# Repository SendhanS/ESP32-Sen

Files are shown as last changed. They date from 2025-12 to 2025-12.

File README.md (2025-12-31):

# ESP32-Sen
A compact ESP32-S3-MINI-1-N8 development board with USB-C (ESD protected), a 4-layer PCB stack-up (signal / GND / power / signal), and 3.3 V regulation using the TLV75801. Includes GPIO buttons, a WS2812B status LED, and space for an onboard I²C OLED breakout.
The board is intended for learning, experimentation, and portfolio demonstration of embedded systems and PCB design practices.
Status: Not yet tested.
The design is functional in theory but may require revisions and improvements after bring-up.

**Overview**

This board provides a clean ESP32-S3 core with USB-C connectivity, proper ESD protection, a structured 4-layer PCB stack-up, and expansion options for basic UI and peripherals. The goal was to move beyond simple 2-layer hobby boards and design something closer to real-world embedded hardware.

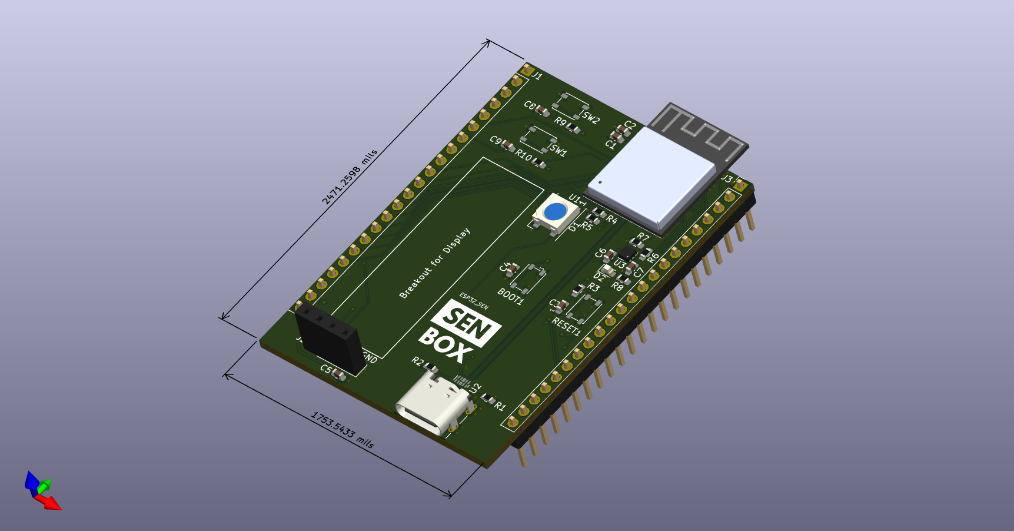
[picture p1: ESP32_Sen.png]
3D render


**Key Features**

ESP32-S3-MINI-1-N8 module

USB-C connector (USB4105)

Differential USB D+ / D− routing

ESD protection using D3V3XA4B10LP TVS diodes

TLV75801 linear regulator (5 V USB → 3.3 V)

4-layer PCB stack-up:

Top: Signal + components

Inner 1: Solid GND plane

Inner 2: Power plane (3.3 V)

Bottom: Signal routing

WS2812B RGB status LED

BOOT and RESET buttons

Two additional GPIO buttons (GPIO4, GPIO5)

**Power Architecture**

Primary power input via USB-C (5 V)

Onboard TLV75801 LDO generates 3.3 V for ESP32 and peripherals

3.3 V rail is exposed on headers for external devices

Design allows future extension for alternative power input with minor modifications

I²C header and reserved space for a 0.91" OLED display module

GPIO headers for expansion

**USB Design Notes**

USB D+ and D− routed as a differential pair

Length-matched and impedance-aware routing

ESD protection placed close to the USB connector

Intended for USB device mode (programming and serial communication)

**I²C and Display Support**

Dedicated I²C header (3.3 V logic)

PCB space reserved for a common 0.91" 128×32 I²C OLED module

Display is optional and not populated by default

**Known Limitations / Future Improvements**

Board has not been fabricated or tested yet

No battery power or charging circuit

No current measurement or power monitoring

Firmware bring-up examples not included yet

OLED mounting footprint may need adjustment depending on module vendor

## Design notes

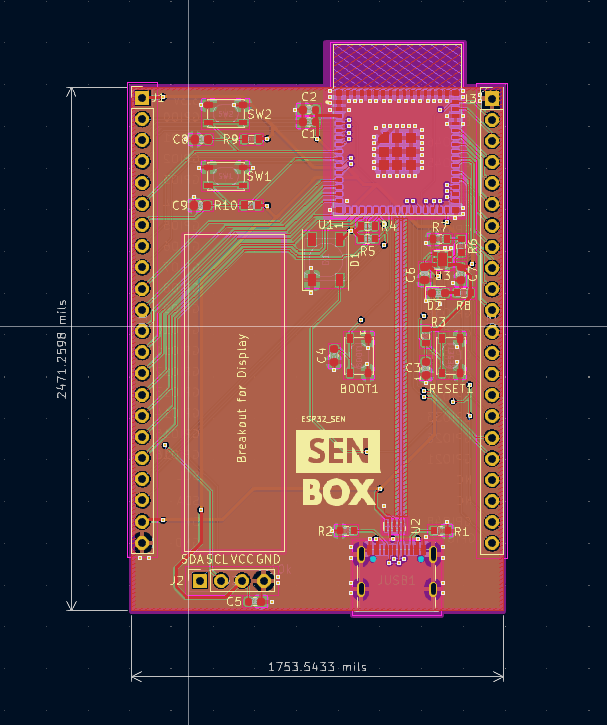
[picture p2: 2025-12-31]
routing.png

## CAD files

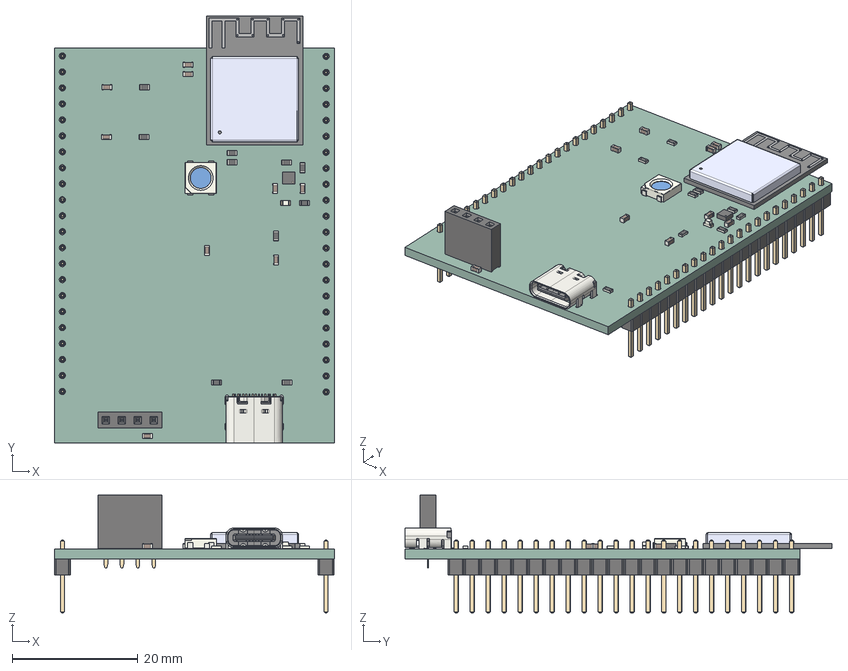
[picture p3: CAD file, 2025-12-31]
ESP32_Sen.step
44.5 x 67.9 x 18.7 mm
C_0603_1608Metric x 9
R_0603_1608Metric x 10
ESP32-S3-MINI-1-N8
LED_WS2812B_PLCC4_50x50mm_P32mm
PinHeader_1x22_P254mm_Vertical x 2
LED_0603_1608Metric
PinSocket_1x04_P2.54mm_Vertical
USB_C_Receptacle_16P_TopMnt_Horizontal_GCT_USB4105-xx-A
WSON_6_1EP_2x2mm_P065mm_EP1x16mm
ESP32_Sen_PCB

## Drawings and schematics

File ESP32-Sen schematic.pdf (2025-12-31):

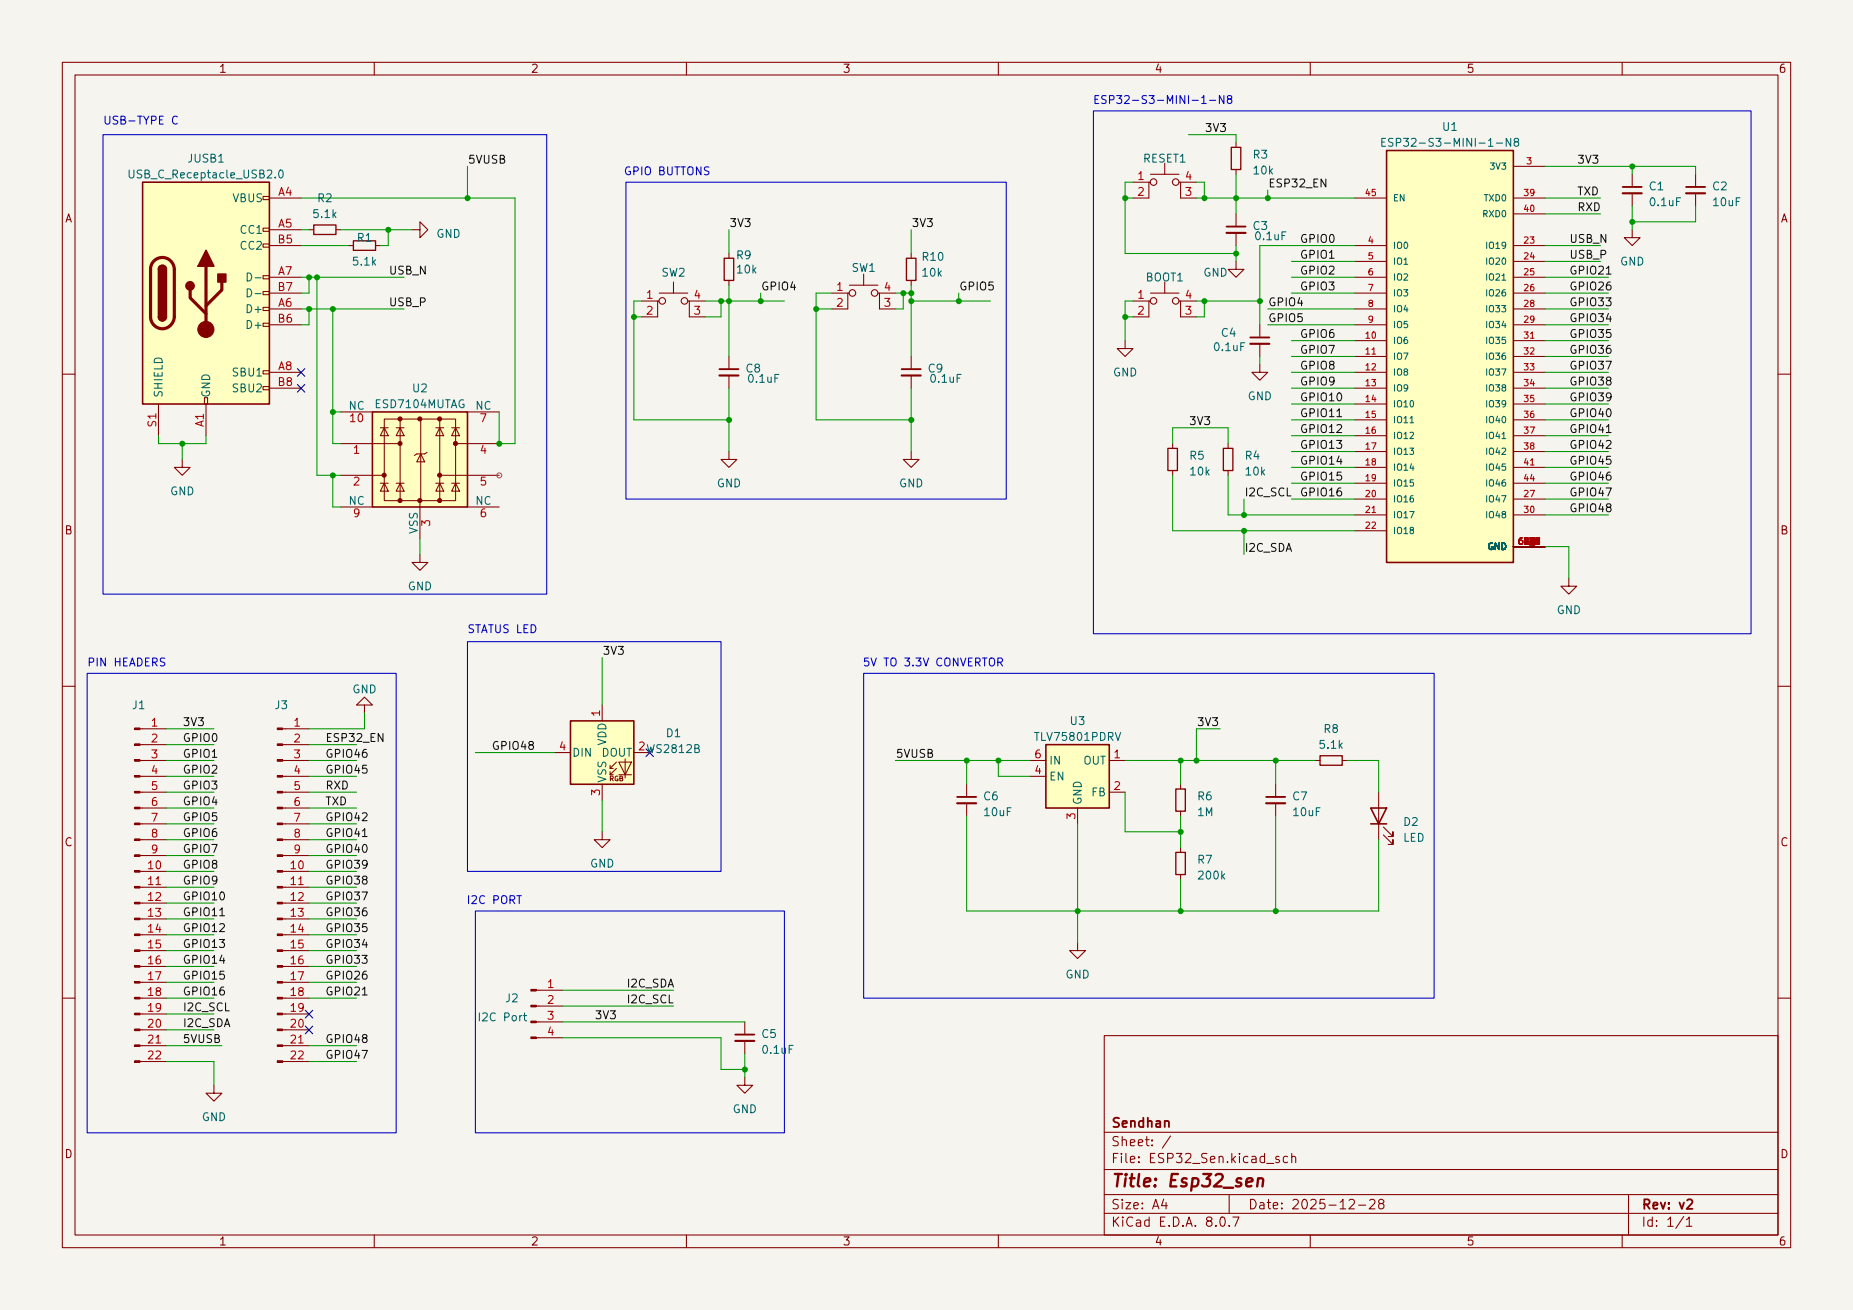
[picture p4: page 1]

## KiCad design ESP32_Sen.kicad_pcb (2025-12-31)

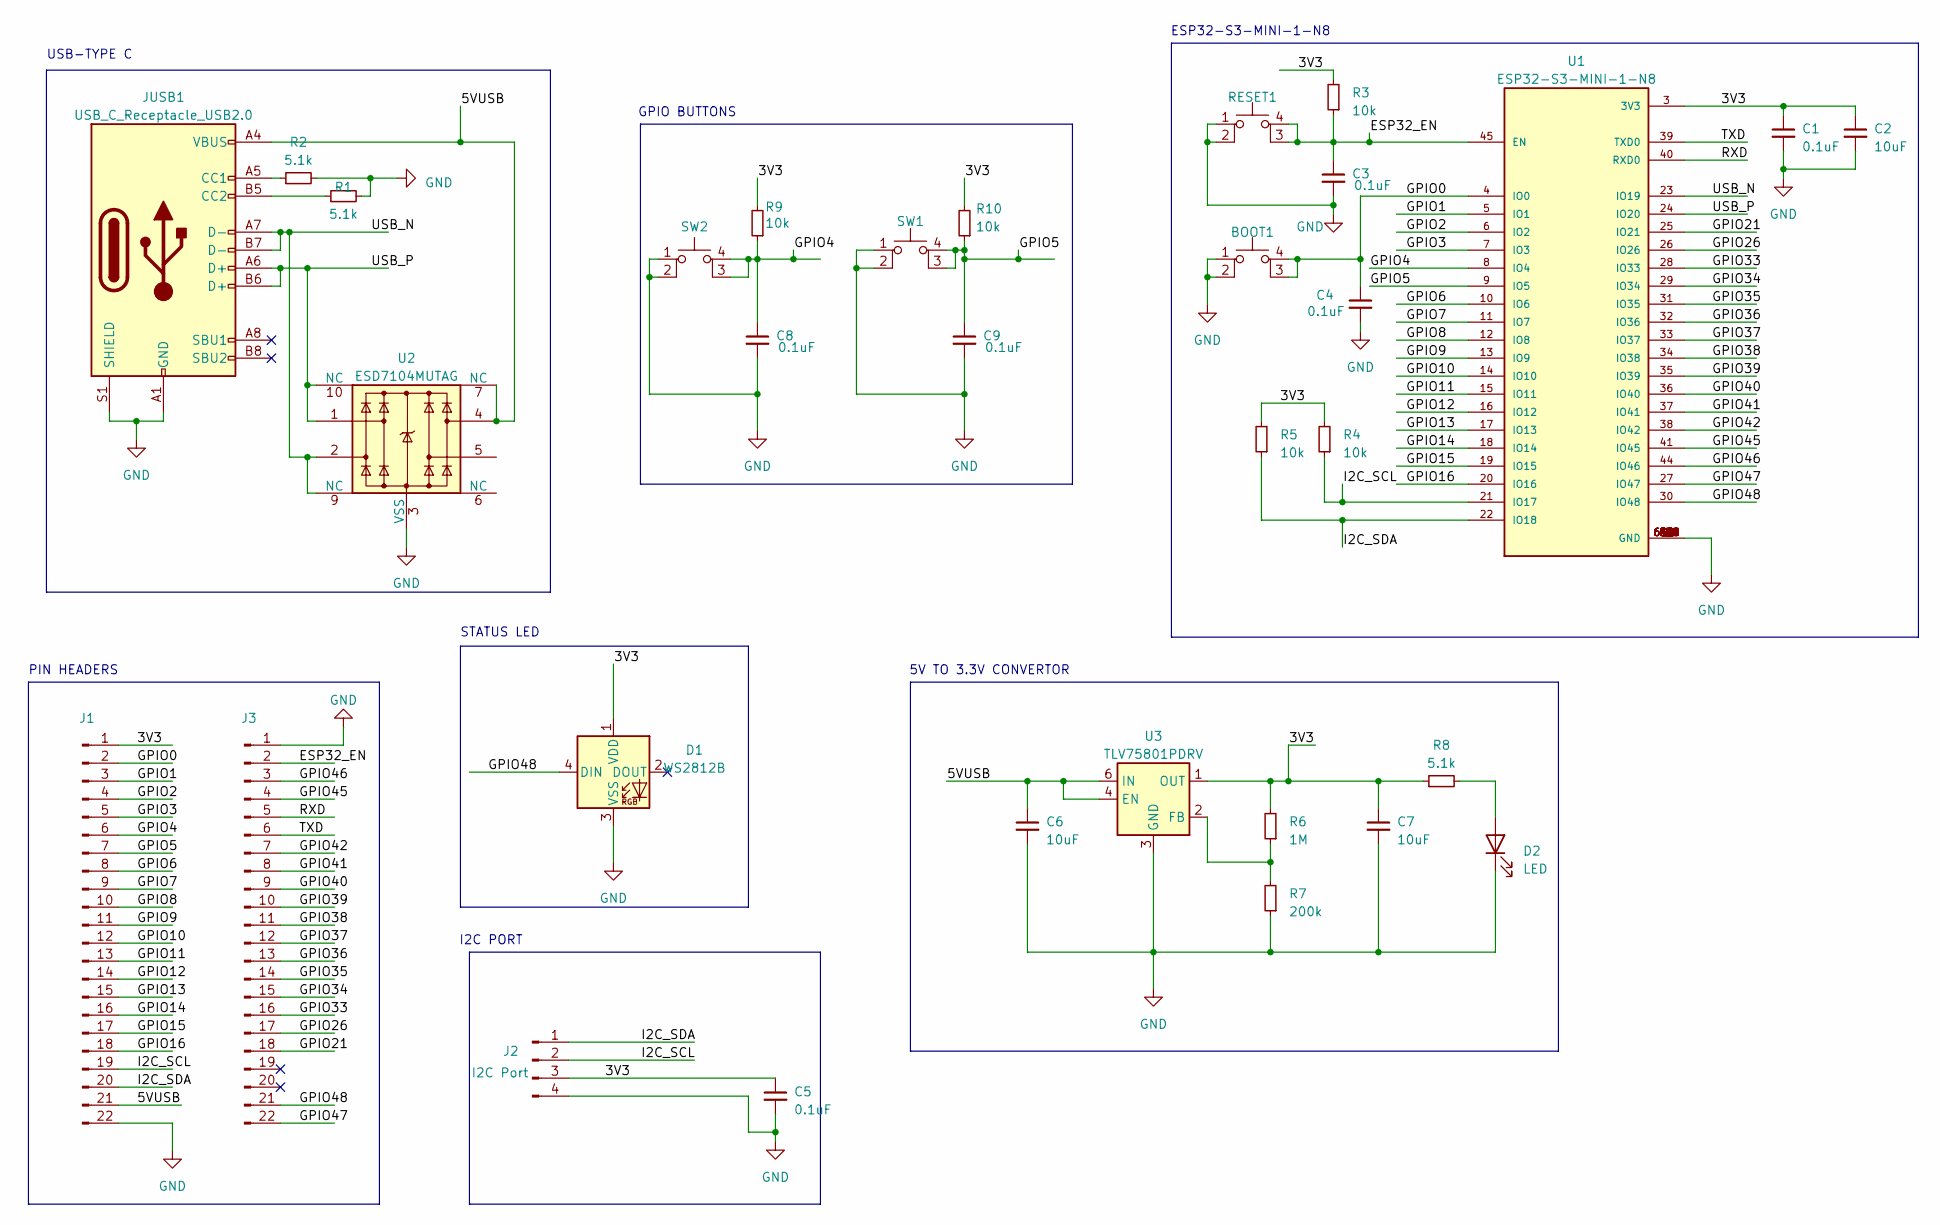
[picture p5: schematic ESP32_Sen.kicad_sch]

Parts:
BOOT1: SW_SPST_PTS810
C1, C3, C4, C5, C8, C9: 0.1uF; C_0603_1608Metric
C2, C6, C7: 10uF; C_0603_1608Metric
D1: WS2812B; LED_WS2812B_PLCC4_5.0x5.0mm_P3.2mm
D2: LED; LED_0603_1608Metric
J1, J3: PinHeader_1x22_P2.54mm_Vertical
J2: I2C Port; PinSocket_1x04_P2.54mm_Vertical
JUSB1: USB_C_Receptacle_USB2.0; USB_C_Receptacle_GCT_USB4105-xx-A_16P_TopMnt_Horizontal
R1, R2, R8: 5.1k; R_0603_1608Metric
R3, R4, R5, R9, R10: 10k; R_0603_1608Metric
R6: 1M; R_0603_1608Metric
R7: 200k; R_0603_1608Metric
RESET1: SW_SPST_PTS810
SW1, SW2: SW_MEC_5E; SW_SPST_PTS810
U1: ESP32-S3-MINI-1-N8; XCVR_ESP32-S3-MINI-1-N8; PARTREV v0.6
U2: ESD7104MUTAG; Diodes_UDFN-10_1.0x2.5mm_P0.5mm
U3: TLV75801PDRV; WSON-6-1EP_2x2mm_P0.65mm_EP1x1.6mm

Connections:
/3V3: C1.1, C2.1, C5.1, C7.1, D1.1 (VDD), J1.1, J2.3, R3.2, R4.2, R5.2, R6.2, R8.1, R9.2, R10.2, U1.3 (3V3), U3.1 (OUT)
/5VUSB: C6.1, J1.21, JUSB1.A4 (VBUS), JUSB1.A9 (VBUS), JUSB1.B4 (VBUS), JUSB1.B9 (VBUS), U2.4, U2.7 (NC), U3.4 (EN), U3.6 (IN)
/ESP32_EN: C3.1, J3.2, R3.1, RESET1.3 (K), RESET1.4 (A), U1.45 (EN)
/GPIO0: BOOT1.3 (K), BOOT1.4 (A), C4.1, J1.2, U1.4 (IO0)
/GPIO1: J1.3, U1.5 (IO1)
/GPIO2: J1.4, U1.6 (IO2)
/GPIO3: J1.5, U1.7 (IO3)
/GPIO4: C8.1, J1.6, R9.1, SW2.3 (K), SW2.4 (A), U1.8 (IO4)
/GPIO5: C9.1, J1.7, R10.1, SW1.3 (K), SW1.4 (A), U1.9 (IO5)
/GPIO6: J1.8, U1.10 (IO6)
/GPIO7: J1.9, U1.11 (IO7)
/GPIO8: J1.10, U1.12 (IO8)
/GPIO9: J1.11, U1.13 (IO9)
/GPIO10: J1.12, U1.14 (IO10)
/GPIO11: J1.13, U1.15 (IO11)
/GPIO12: J1.14, U1.16 (IO12)
/GPIO13: J1.15, U1.17 (IO13)
/GPIO14: J1.16, U1.18 (IO14)
/GPIO15: J1.17, U1.19 (IO15)
/GPIO16: J1.18, U1.20 (IO16)
/GPIO21: J3.18, U1.25 (IO21)
/GPIO26: J3.17, U1.26 (IO26)
/GPIO33: J3.16, U1.28 (IO33)
/GPIO34: J3.15, U1.29 (IO34)
/GPIO35: J3.14, U1.31 (IO35)
/GPIO36: J3.13, U1.32 (IO36)
/GPIO37: J3.12, U1.33 (IO37)
/GPIO38: J3.11, U1.34 (IO38)
/GPIO39: J3.10, U1.35 (IO39)
/GPIO40: J3.9, U1.36 (IO40)
/GPIO41: J3.8, U1.37 (IO41)
/GPIO42: J3.7, U1.38 (IO42)
/GPIO45: J3.4, U1.41 (IO45)
/GPIO46: J3.3, U1.44 (IO46)
/GPIO47: J3.22, U1.27 (IO47)
/GPIO48: D1.4 (DIN), J3.21, U1.30 (IO48)
/I2C_SCL: J1.19, J2.2, R4.1, U1.21 (IO17)
/I2C_SDA: J1.20, J2.1, R5.1, U1.22 (IO18)
/RXD: J3.5, U1.40 (RXD0)
/TXD: J3.6, U1.39 (TXD0)
/USB_N: JUSB1.A7 (D-), JUSB1.B7 (D-), U1.23 (IO19), U2.2, U2.9 (NC)
/USB_P: JUSB1.A6 (D+), JUSB1.B6 (D+), U1.24 (IO20), U2.1, U2.10 (NC)
GND: BOOT1.1, BOOT1.2, C1.2, C2.2, C3.2, C4.2, C5.2, C6.2, C7.2, C8.2, C9.2, D1.3 (VSS), D2.1 (K), J1.22, J2.4, J3.1, JUSB1.A1 (GND), JUSB1.A12 (GND), JUSB1.B1 (GND), JUSB1.B12 (GND), JUSB1.S1 (SHIELD), R1.2, R2.2, R7.1, RESET1.1, RESET1.2, SW1.1, SW1.2, SW2.1, SW2.2, U1.1 (GND), U1.2 (GND), U1.42 (GND), U1.43 (GND), U1.46 (GND), U1.47 (GND), U1.48 (GND), U1.49 (GND), U1.50 (GND), U1.51 (GND), U1.52 (GND), U1.53 (GND), U1.54 (GND), U1.55 (GND), U1.56 (GND), U1.57 (GND), U1.58 (GND), U1.59 (GND), U1.60 (GND), U1.61 (GND), U1.61_1 (GND), U1.61_2 (GND), U1.61_3 (GND), U1.61_4 (GND), U1.61_5 (GND), U1.61_6 (GND), U1.61_7 (GND), U1.61_8 (GND), U1.62 (GND), U1.63 (GND), U1.64 (GND), U1.65 (GND), U2.3 (VSS), U2.8 (VSS), U3.3 (GND), U3.7 (GND)
unnamed: D2.2 (A), R8.2
unnamed: JUSB1.A5 (CC1), R2.1
unnamed: JUSB1.B5 (CC2), R1.1
unnamed: R6.1, R7.2, U3.2 (FB)

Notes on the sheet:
STATUS LED
ESP32-S3-MINI-1-N8
PIN HEADERS
5V TO 3.3V CONVERTOR
GPIO BUTTONS
USB-TYPE C
I2C PORT

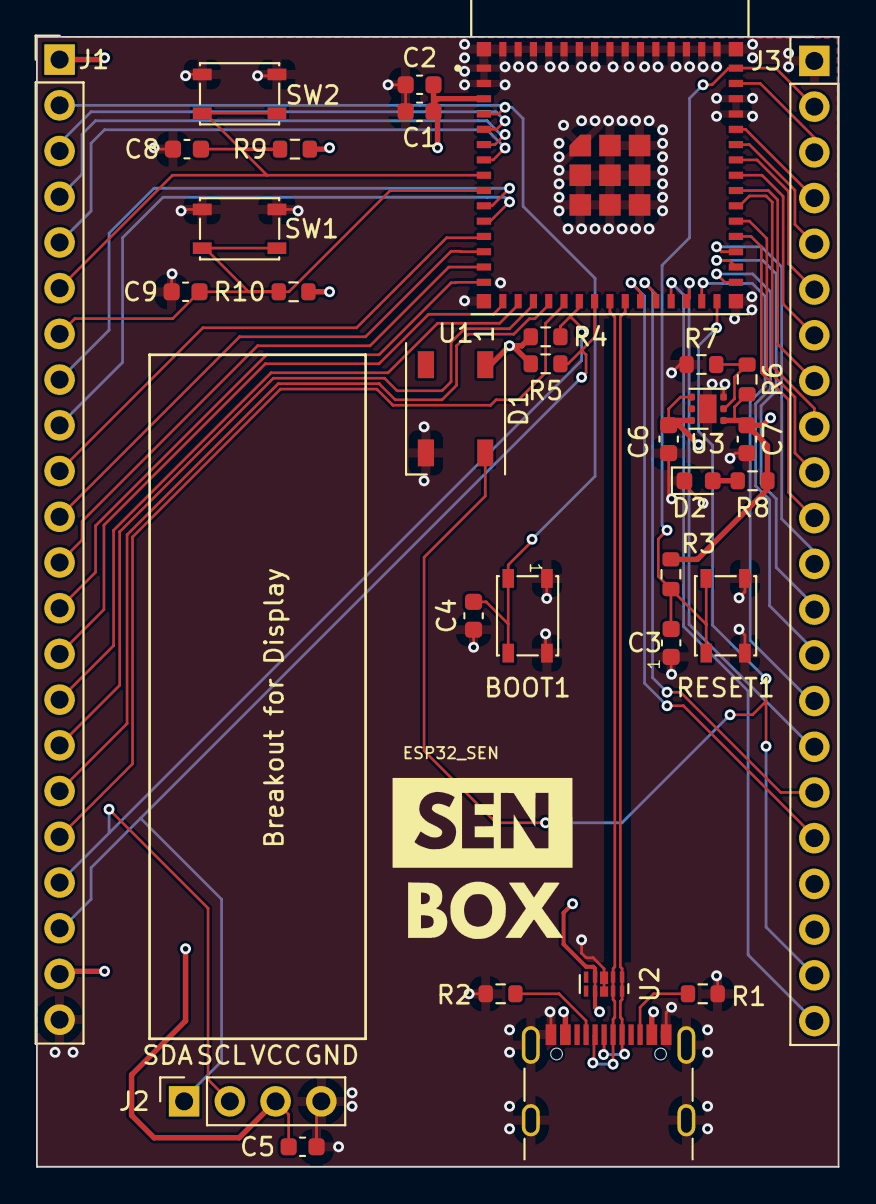
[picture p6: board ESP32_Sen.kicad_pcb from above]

Board: 4 copper layers, 44.5 x 62.8 mm, 32 parts (0 on the bottom side), 47 nets.
